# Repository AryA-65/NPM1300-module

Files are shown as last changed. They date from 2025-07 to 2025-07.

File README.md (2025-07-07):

# NPM1300-module (General Doc)
The nPM1300 is a power management IC created and sold by Nordic Semi, intended to be paired with their nRF lineup but can be used by any microcontroller. The nPM1300-module is a 3rd party module that is similar to and based on a reference PCB provided by Nordic Semi. This module allows for simplified testing and cost effective prototyping of a power management IC into a project.

## Board Info (Rev_2)
<table>
  <tr>
    <td>
Current specifications:

- 25.8mm x 25.8mm footprint  
- 7 breakout pins per side  
- Buck converters and LDOs enabled (buck converter voltage is set by placing a resistor on the appropriate Vset pin, check page 47 in the nPM1300 datasheet)  
- Onboard programmable LED
    </td>
    <td>
      <br>
      
  </tr>
</table>

## Updates
Older revisions can be found in "archive" branch:
- Reduced footprint size from 26.5mm x 29.5mm to 25.8mm x 25.8mm
- Added onboard led, and bypass for external led
- Simplified layout, reducing number of total pins
- Added footprints for I2C pullup resistors (short pins for external pullup resistors)
- Flipped board layout
- Reduced GND pin count from 9 to 3

## Schematic
Based off of Nordic's own reference schematic


## Symbol and Footprint
*In progress*

## Software
*Software example code in progress*

## Disclaimer
I OWN NONE OF THE RIGHTS TO THE NPM1300, IT IS A PRODUCT MADE AND SOLD BY NORDIC SEMI. THIS BOARD IS INTENDED TO MAKE INTEGRATION OF THE IC SIMPLER AND HASTLE FREE.

## Documents and Links
List of all documents related to the board:
- [Nordic Semi nPM1300](https://www.nordicsemi.com/Products/nPM1300)
- [nPM1300 reference layouts, production files and BOM](https://www.nordicsemi.com/Products/nPM1300/Downloads#infotabs)
- [Other documentation related to the nPM1300](https://docs.nordicsemi.com/category/npm1300-category)
- [Full nPM1300 datasheet](https://mm.digikey.com/Volume0/opasdata/d220001/medias/docus/6443/NPM1300-QEAA-R.pdf)

## Previous Revisions
- [Rev_1](https://github.com/AryA-65/NPM1300-module/tree/archive)

## License
This project uses the [MIT License](https://github.com/AryA-65/NPM1300-module/blob/main/LICENSE).

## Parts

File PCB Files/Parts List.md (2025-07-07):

## List of all the parts
|Part Name|Part Size|Part Specs|Link|Quantity|
|---|---|---|----|---|

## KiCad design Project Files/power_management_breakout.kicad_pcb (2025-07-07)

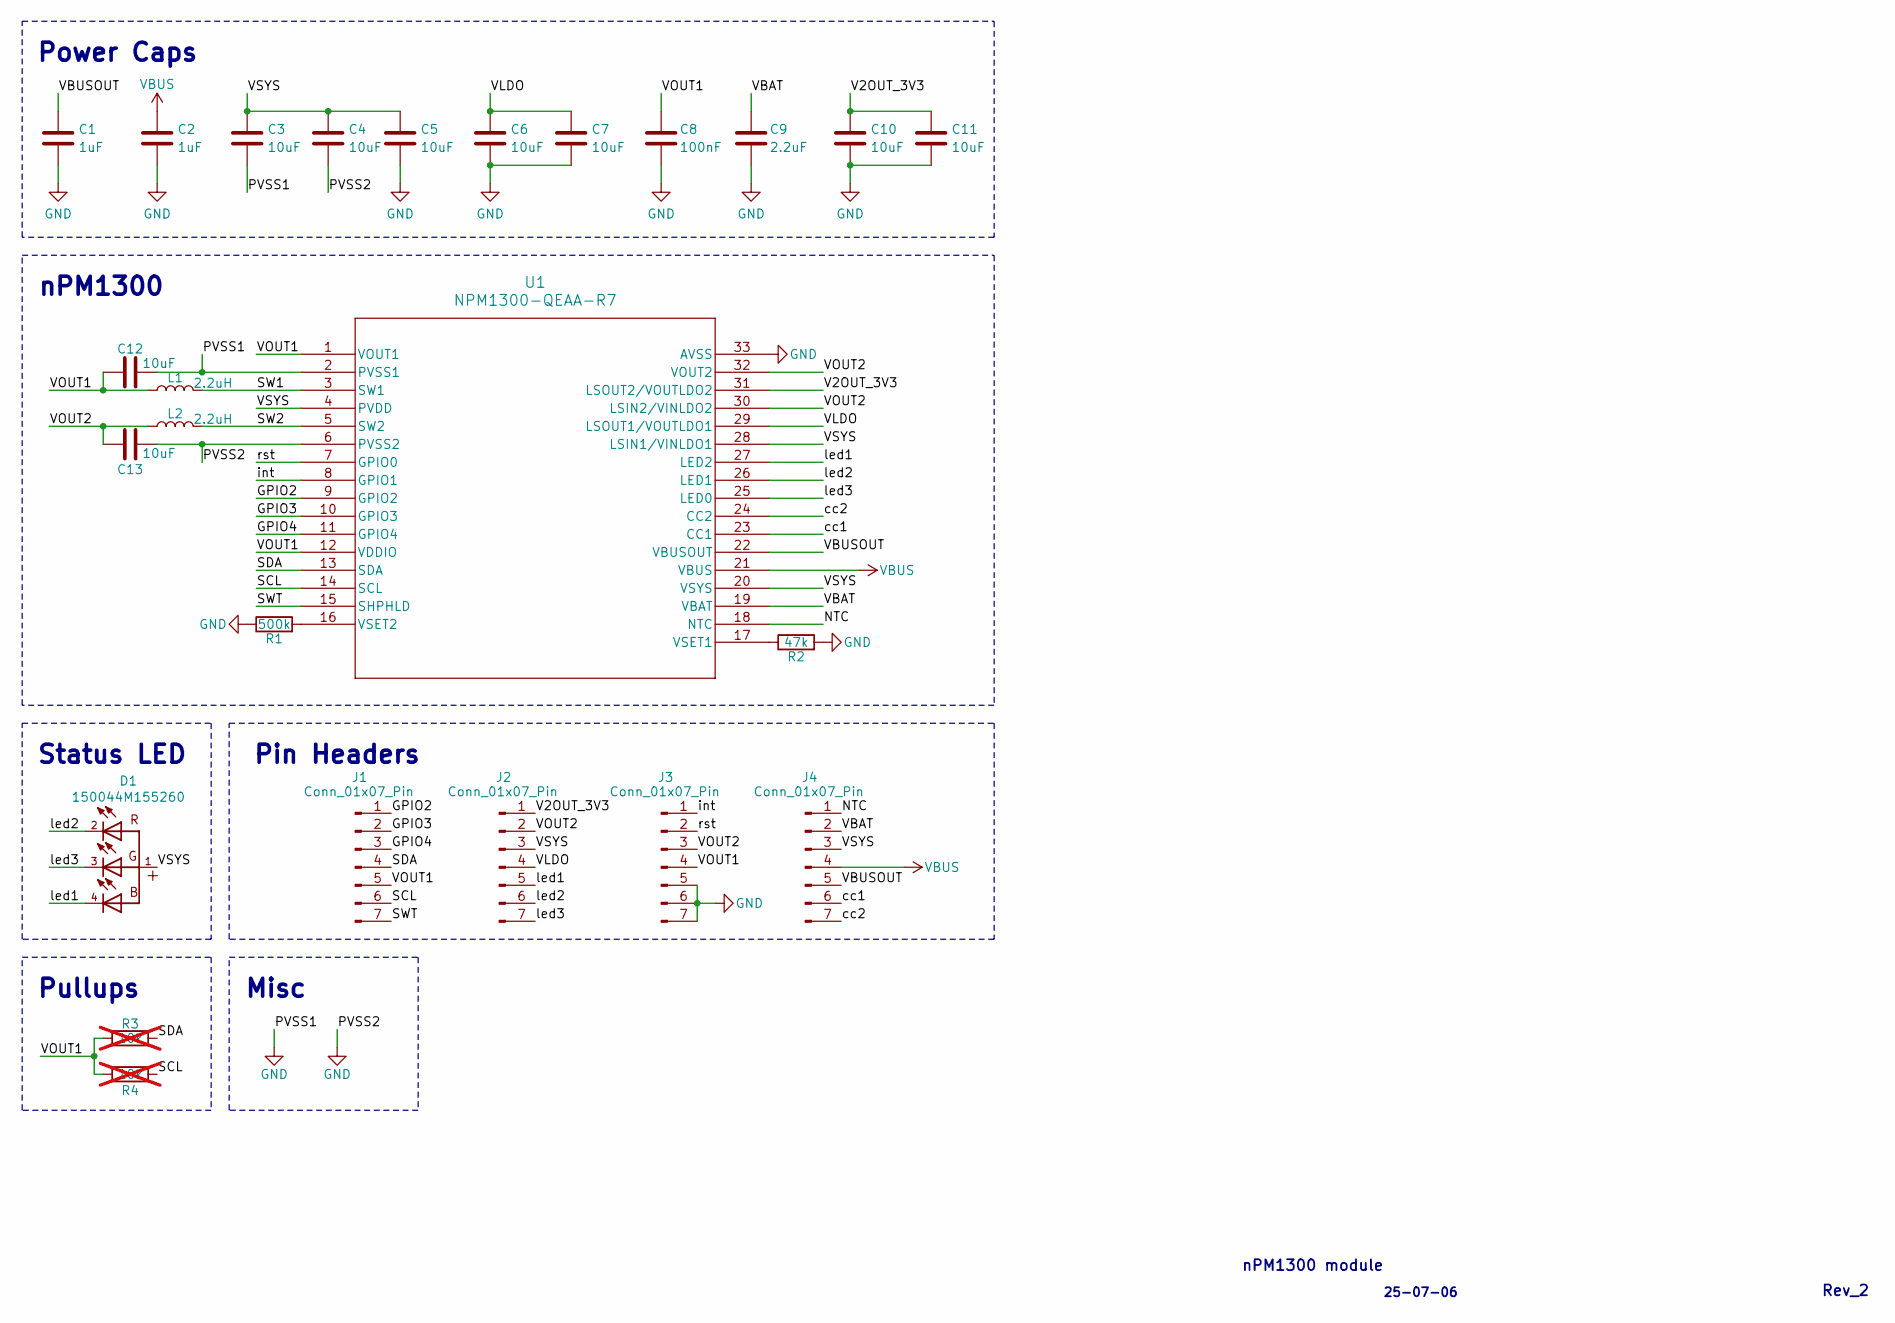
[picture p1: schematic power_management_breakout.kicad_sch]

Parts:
C1, C2: 1uF; C_0603_1608Metric
C3, C4, C5, C6, C7, C10, C11, C12, C13: 10uF; C_0603_1608Metric
C8: 100nF; C_0201_0603Metric
C9: 2.2uF; C_0603_1608Metric
D1: 150044M155260
J1, J2, J3, J4: Conn_01x07_Pin; PinHeader_1x07_P2.54mm_Vertical
L1, L2: 2.2uH; INDC2016X100N
R1: 500k; R_0201_0603Metric
R2: 47k; R_0201_0603Metric; LCSC C138139
R3, R4: 10k; R_0201_0603Metric; not fitted
U1: NPM1300-QEAA-R7; QFN32_5X5_NOR

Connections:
/GPIO2: J1.1, U1.9 (GPIO2)
/GPIO3: J1.2, U1.10 (GPIO3)
/GPIO4: J1.3, U1.11 (GPIO4)
/NTC: J4.1, U1.18 (NTC)
/SCL: J1.6, R4.2, U1.14 (SCL)
/SDA: J1.4, R3.2, U1.13 (SDA)
/SW1: L1.2, U1.3 (SW1)
/SW2: L2.2, U1.5 (SW2)
/SWT: J1.7, U1.15 (SHPHLD)
/V2OUT_3V3: C10.1, C11.1, J2.1, U1.31 (LSOUT2/VOUTLDO2)
/VBAT: C9.1, J4.2, U1.19 (VBAT)
/VBUSOUT: C1.1, J4.5, U1.22 (VBUSOUT)
/VLDO: C6.1, C7.1, J2.4, U1.29 (LSOUT1/VOUTLDO1)
/VOUT1: C8.1, C12.1, J1.5, J3.4, L1.1, R3.1, R4.1, U1.1 (VOUT1), U1.12 (VDDIO)
/VOUT2: C13.1, J2.2, J3.3, L2.1, U1.30 (LSIN2/VINLDO2), U1.32 (VOUT2)
/VSYS: C3.1, C4.1, C5.1, D1.1, J2.3, J4.3, U1.4 (PVDD), U1.20 (VSYS), U1.28 (LSIN1/VINLDO1)
/cc1: J4.6, U1.23 (CC1)
/cc2: J4.7, U1.24 (CC2)
/int: J3.1, U1.8 (GPIO1)
/led1: D1.4, J2.5, U1.27 (LED2)
/led2: D1.2, J2.6, U1.26 (LED1)
/led3: D1.3, J2.7, U1.25 (LED0)
/rst: J3.2, U1.7 (GPIO0)
GND: C1.2, C2.2, C3.2, C4.2, C5.2, C6.2, C7.2, C8.2, C9.2, C10.2, C11.2, C12.2, C13.2, J3.5, J3.6, J3.7, R1.1, R2.2, U1.2 (PVSS1), U1.6 (PVSS2), U1.33 (AVSS)
unnamed: R2.1, U1.17 (VSET1)
unnamed: R1.2, U1.16 (VSET2)
VBUS: C2.1, J4.4, U1.21 (VBUS)

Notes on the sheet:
Power Caps
Pin Headers
Pullups
Status LED
25-07-06
nPM1300 module
Misc
Rev_2
nPM1300

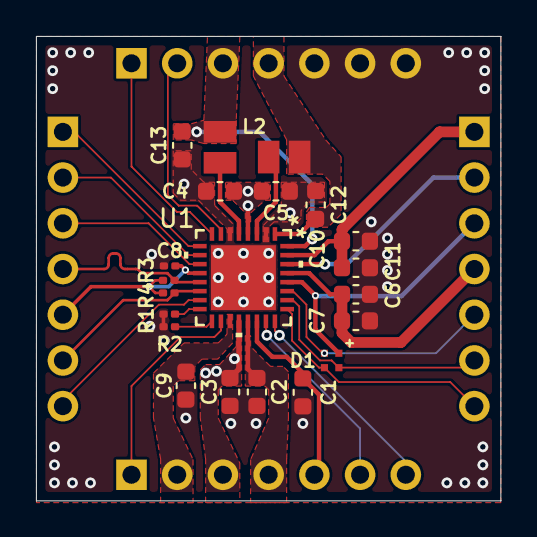
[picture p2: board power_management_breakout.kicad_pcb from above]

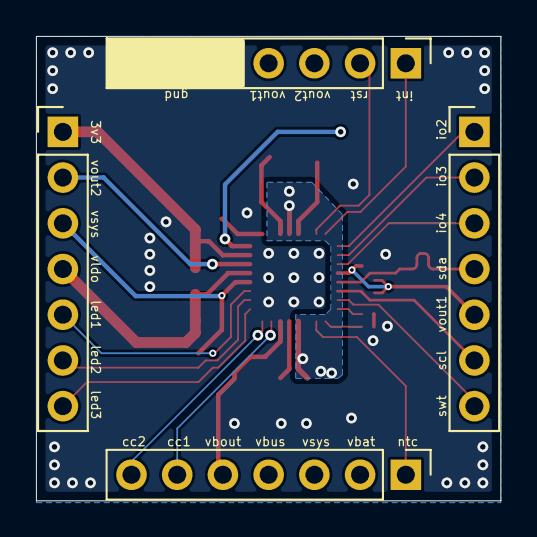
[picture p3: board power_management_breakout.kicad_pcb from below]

Board: 2 copper layers, 25.8 x 25.8 mm, 25 parts (4 on the bottom side), 27 nets.

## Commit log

2025-07-01 Added all project files
    [power_management_breakout.csv, power_management_breakout.kicad_pcb, power_management_breakout.kicad_sch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]
2025-07-01 Added doc files
    [npm1300_qeaa_config1_bom.xls]
2025-07-07 Cleaned main branch, all previous files in archive
    [npm1300_qeaa_config1_bom.xls, power_management_breakout.csv, power_management_breakout.kicad_pcb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]
